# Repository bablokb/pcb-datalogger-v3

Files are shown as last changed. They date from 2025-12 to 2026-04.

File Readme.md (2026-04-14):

KiCAD-Designfiles for Version 3 PCB
===================================

Here are the KiCAD (v7) design-files for the Datalogger-V3-PCB.

The PCB supports a
[display-adapter](https://github.com/bablokb/pcb-datalogger-display-adapter)
connected with SURS-cables, or an [adapter connected with normal
DuPont-sockets](https://github.com/bablokb/pcb-datalogger-display-adapter-v2).

Schematic
---------

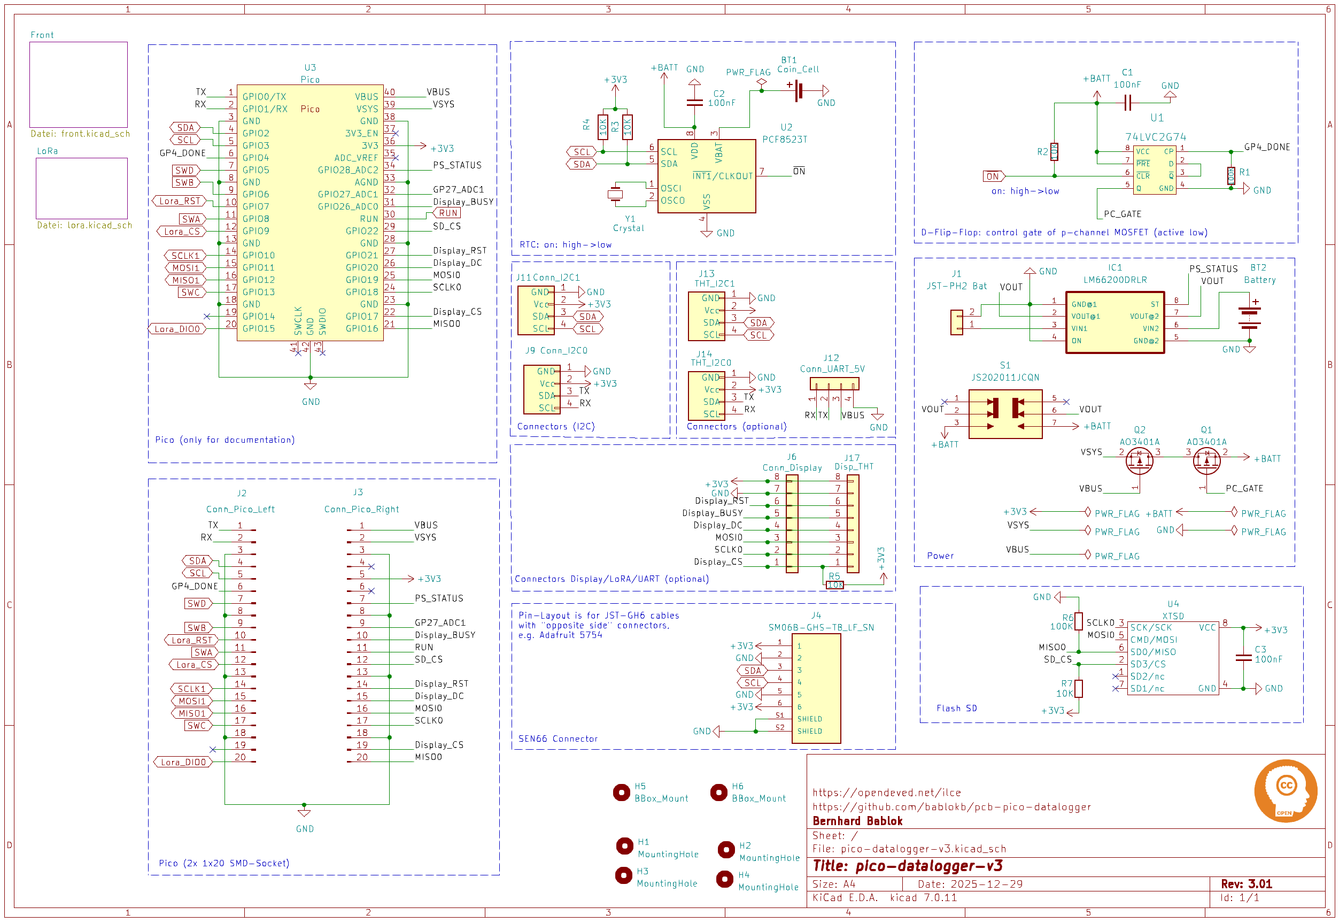
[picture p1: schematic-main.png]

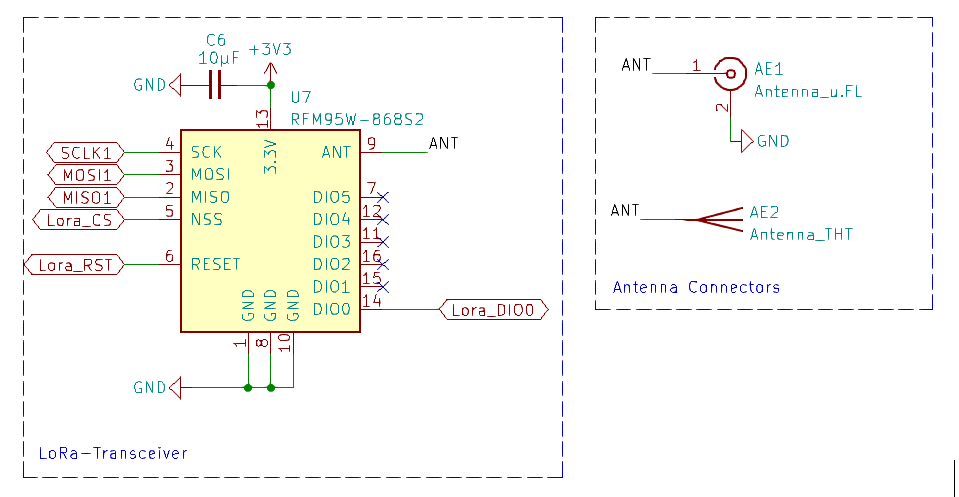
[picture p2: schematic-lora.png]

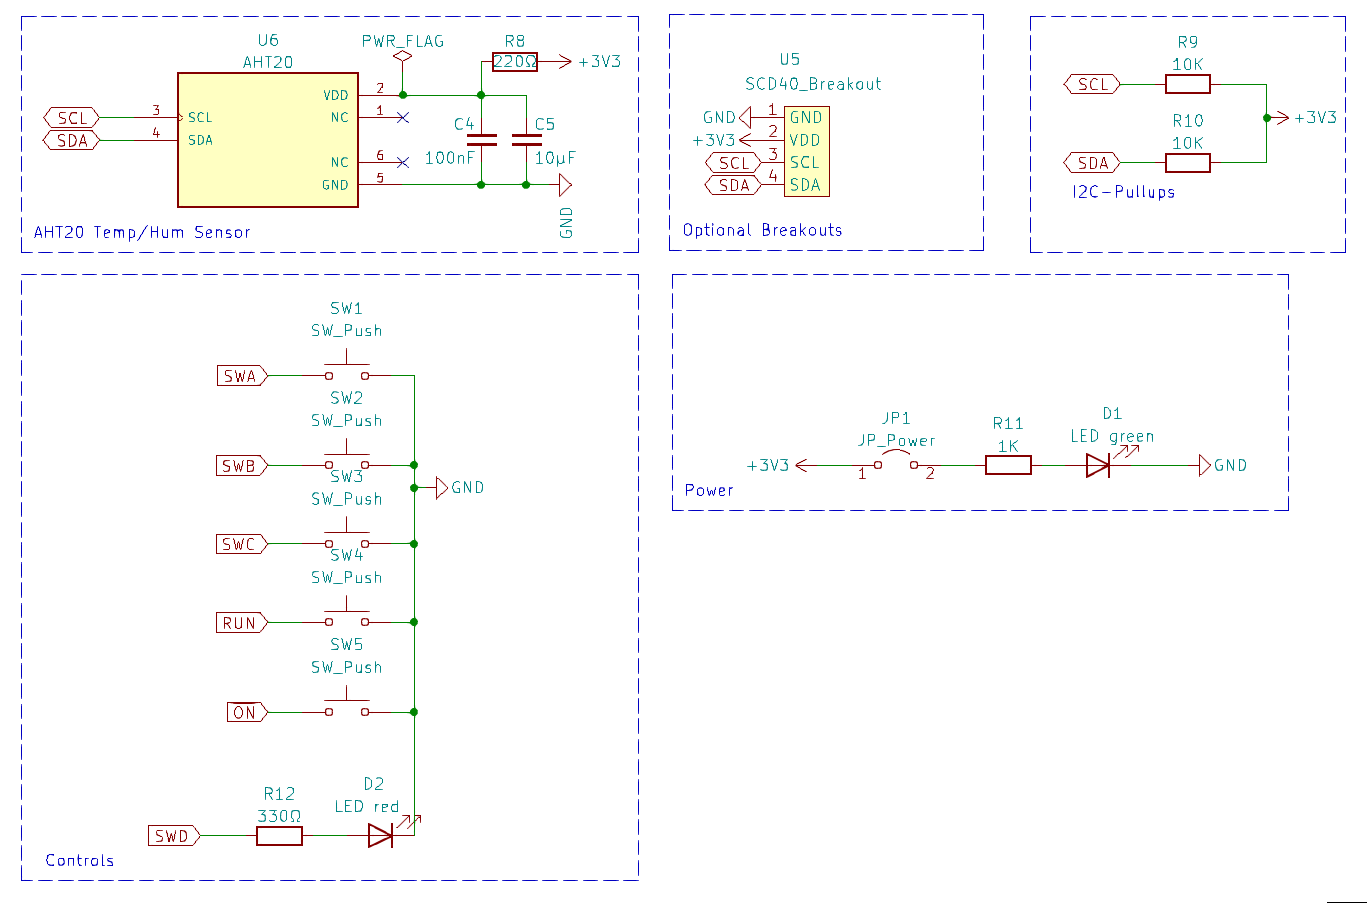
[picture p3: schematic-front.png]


Layout
------

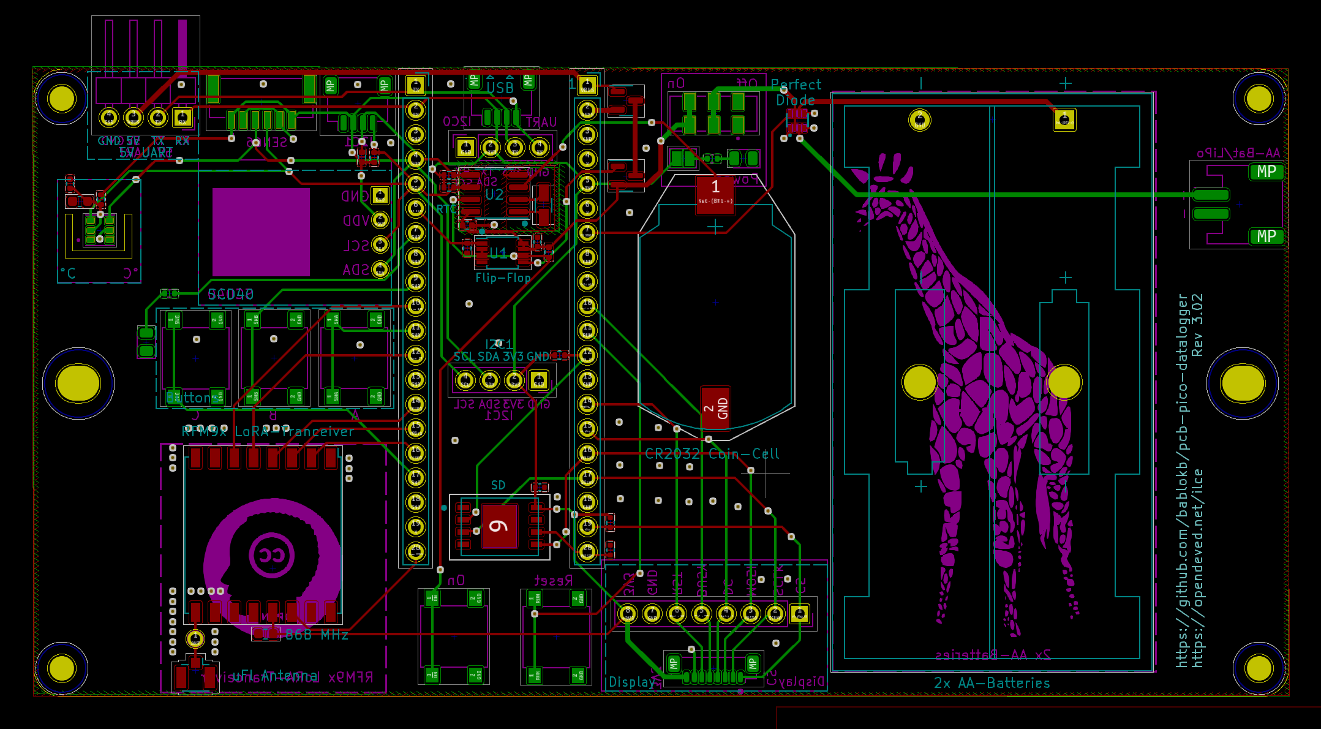
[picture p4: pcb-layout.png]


3D-Views
--------

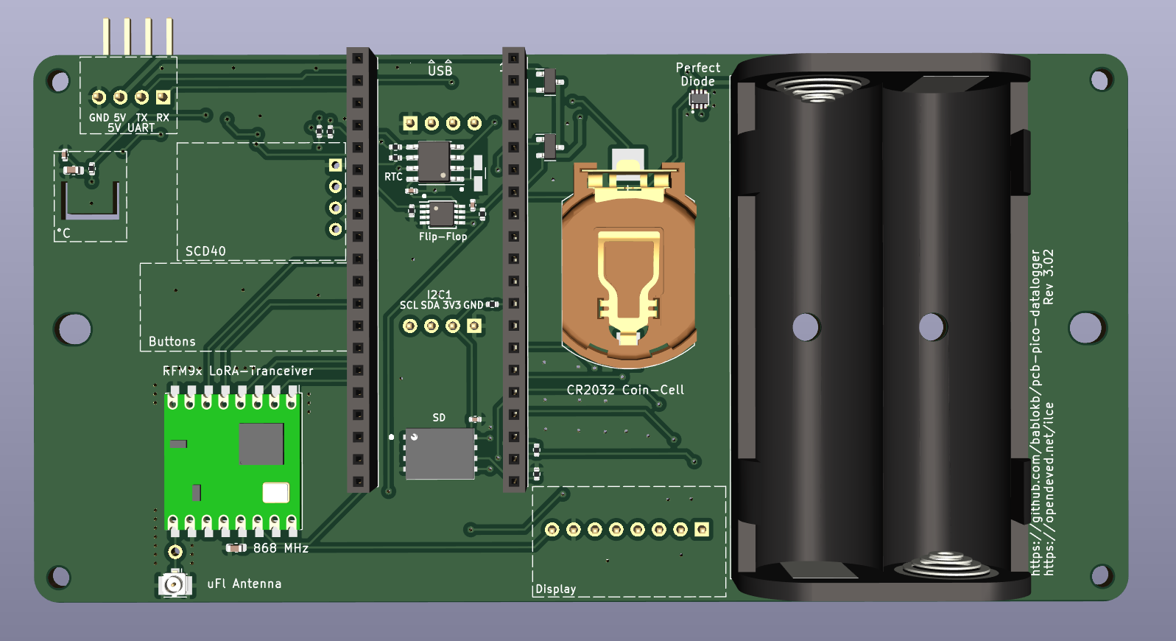
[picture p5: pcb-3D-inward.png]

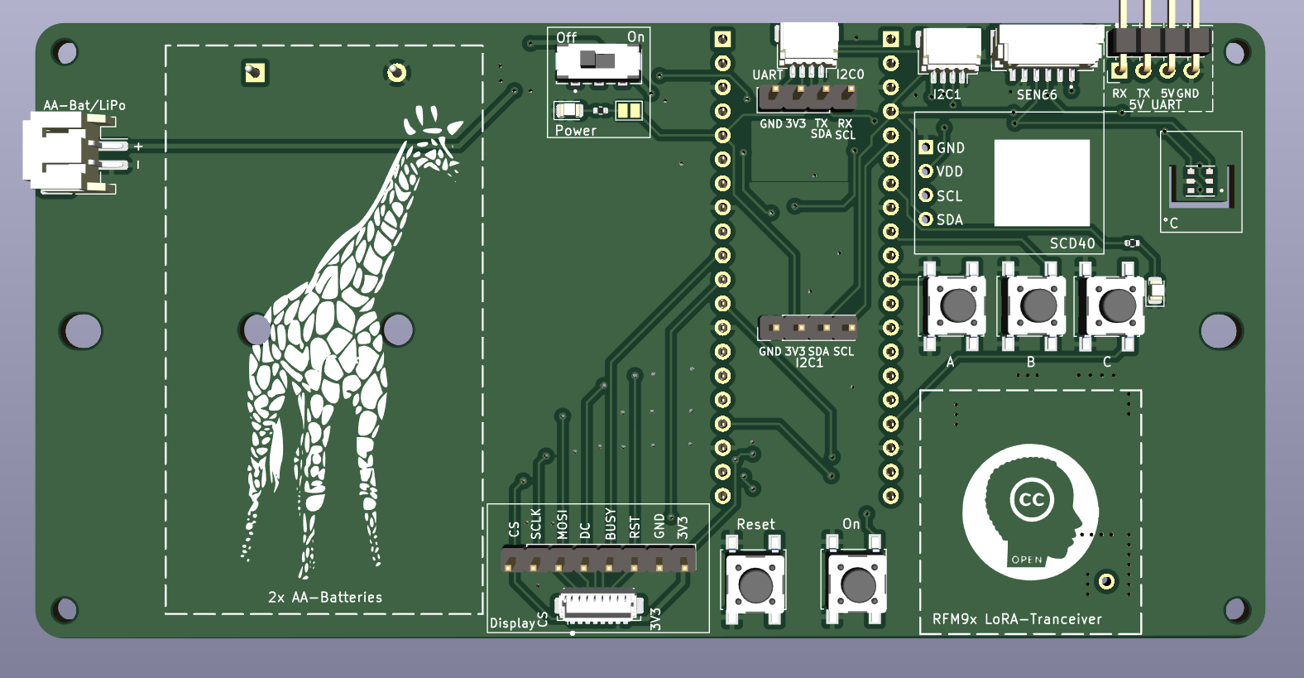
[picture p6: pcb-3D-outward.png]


Printed Case
------------

A printed case is available from <https://github.com/bablokb/3D-datalogger-v3-case>:



Together with a display:



License
-------

[![CC BY-SA 4.0][cc-by-sa-shield]][cc-by-sa]

This work is licensed under a
[Creative Commons Attribution-ShareAlike 4.0 International
License][cc-by-sa].

[][cc-by-sa]

[cc-by-sa]: http://creativecommons.org/licenses/by-sa/4.0/
[cc-by-sa-image]: https://licensebuttons.net/l/by-sa/4.0/88x31.png
[cc-by-sa-shield]:
https://img.shields.io/badge/License-CC%20BY--SA%204.0-lightgrey.svg

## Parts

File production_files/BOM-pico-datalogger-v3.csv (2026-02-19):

Comment | Designator | Footprint | LCSC
1K | R11 | R_0402_1005Metric | C11702
SM06B-GHS-TB_LF_SN | J4 | JST_SM06B-GHS-TB_LF_SN | C133065
AO3401A | Q1,Q2 | SOT-23 | C15127
100nF | C1,C2,C3,C4 | C_0402_1005Metric | C1525
Conn_I2C1 | J11,J9 | JST_SH_SM04B-SRSS-TB_1x04-1MP_P1.00mm_Horizontal | C160404
10µF | C5,C6 | C_0603_1608Metric | C19702
JS202011JCQN | S1 | SW_JS202011JCQN | C221665
SW_Push | SW1,SW2,SW3,SW4,SW5 | SW_SPST_B3S-1000 | C221869
LED green | D1 | LED_0805_2012Metric | C2297
220Ω | R8 | R_0402_1005Metric | C25091
330Ω | R12 | R_0402_1005Metric | C25104
100K | R1,R6 | R_0402_1005Metric | C25741
10K | R10,R2,R3,R4,R5,R7,R9 | R_0402_1005Metric | C25744
PCF8523T | U2 | SOIC-8_3.9x4.9mm_P1.27mm | C2651516
RFM95W-868S2 | U7 | HOPERF_RFM9XW_SMD | C2844472
JST-PH2 Bat | J1 | JST_PH_S2B-PH-SM4-TB_1x02-1MP_P2.00mm_Horizontal | C295747
AHT20 | U6 | AHT20 | C3012622
Battery | BT2 | BatteryHolder_Keystone_2462_2xAA | C3029547
Crystal | Y1 | Crystal_SMD_3215-2Pin_3.2x1.5mm | C32346
LM66200DRLR | IC1 | LM66200DRLR | C3235556
Conn_Pico_Left | J2,J3 | PinSocket_1x20_P2.54mm_Vertical | C429947
Conn_Display | J6 | JST_SUR_BM08B-SURS-TF_1x08-1MP_P0.80mm_Vertical | C5143489
74LVC2G74 | U1 | X2SON-8_1.4x1mm_P0.35mm | C548678
XTSD | U4 | XTSD | C7429710
LED red | D2 | LED_0805_2012Metric | C84256
Antenna_u.FL | AE1 | U.FL_Hirose_U.FL-R-SMT-1_Vertical | C88374
Coin_Cell | BT1 | CR2032_Holder | C964777

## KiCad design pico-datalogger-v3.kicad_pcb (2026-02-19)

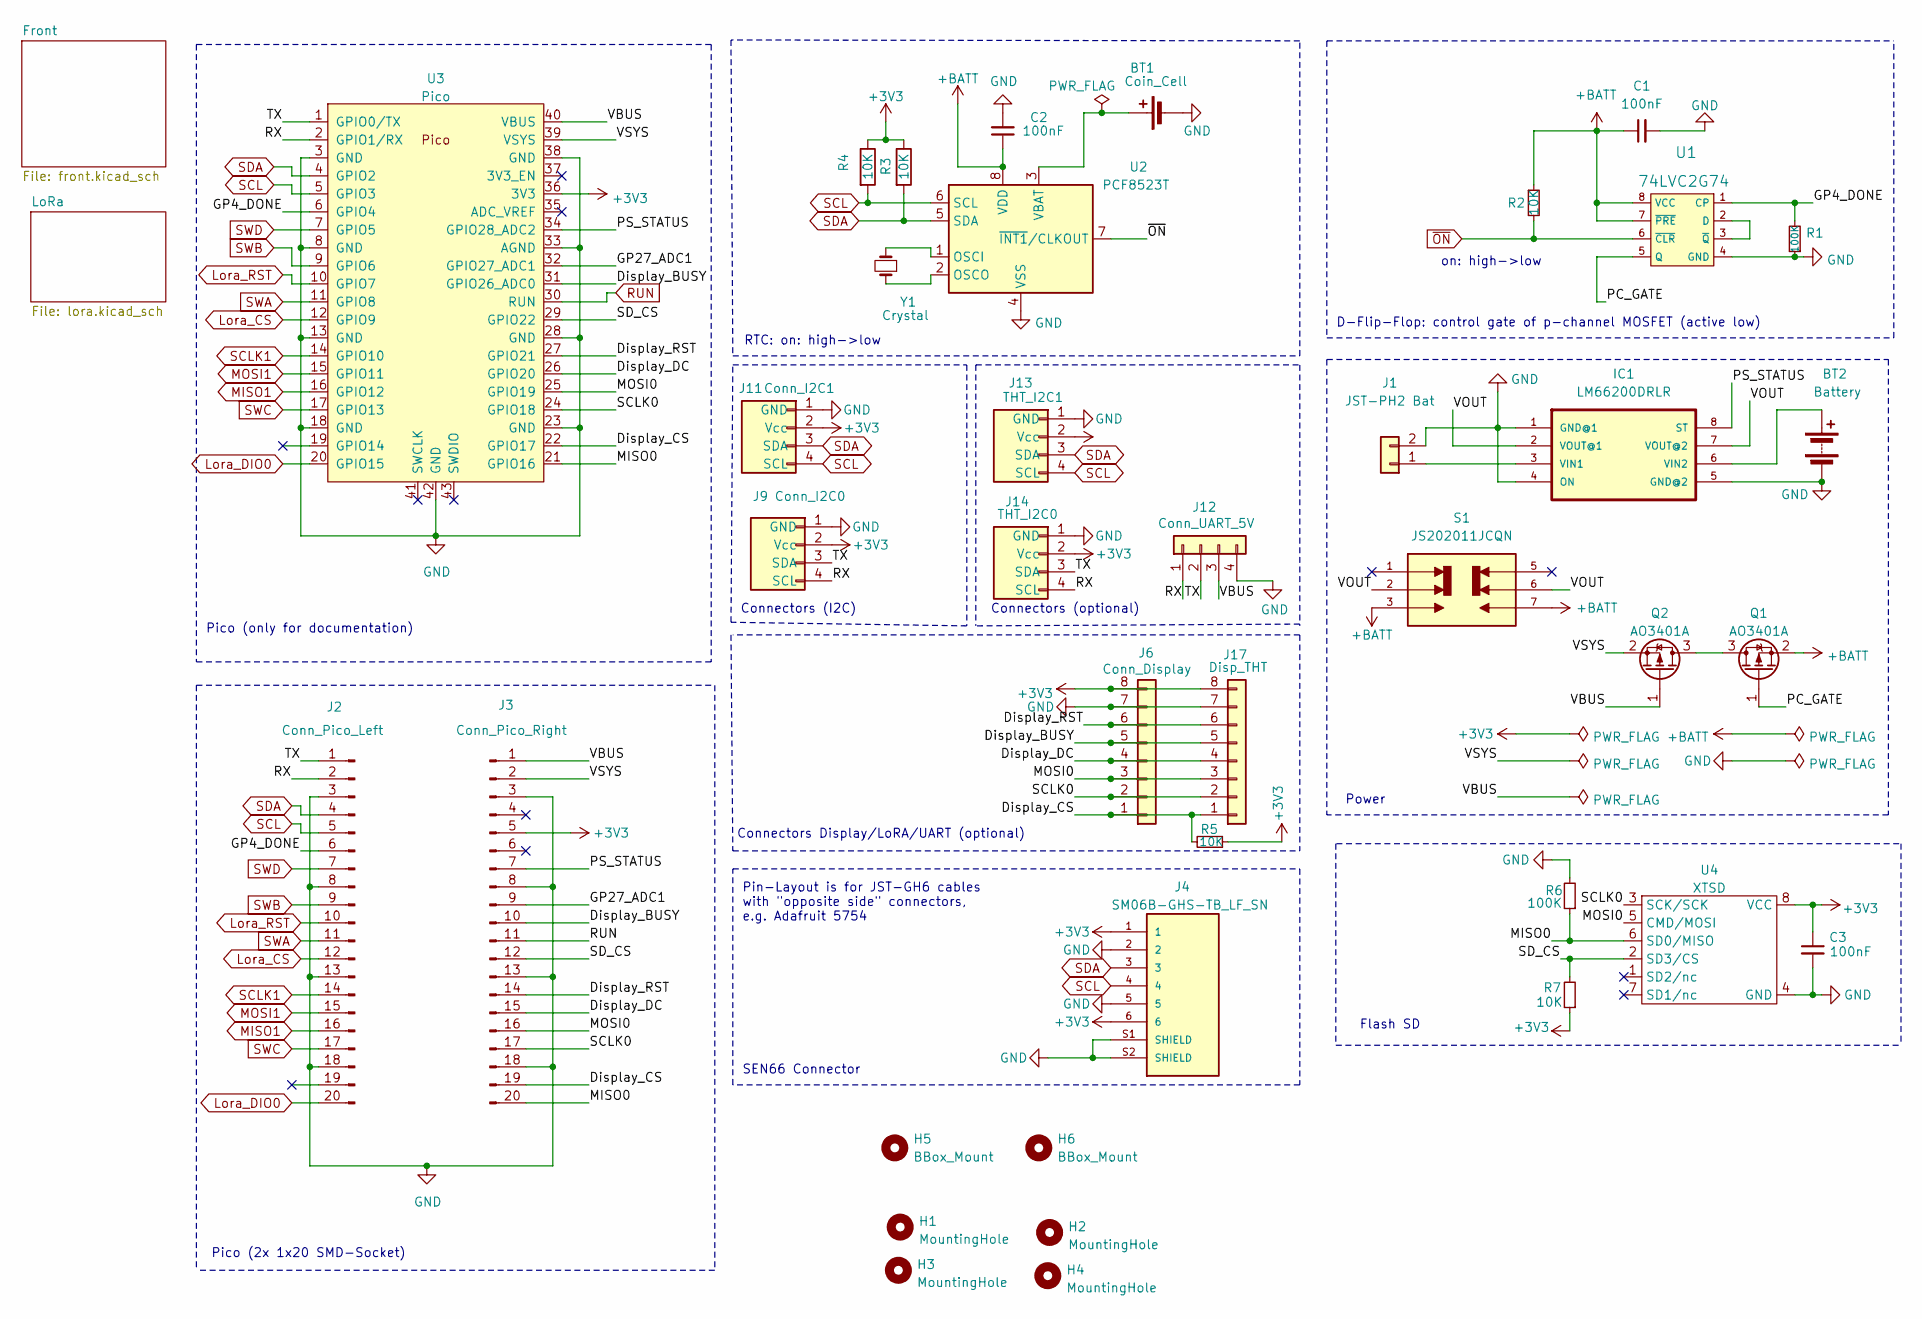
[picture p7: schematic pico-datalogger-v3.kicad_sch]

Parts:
BT1: Coin_Cell; CR2032_Holder; LCSC C964777
BT2: Battery; BatteryHolder_Keystone_2462_2xAA; LCSC C3029547
C1, C2, C3: 100nF; C_0402_1005Metric; LCSC C1525
H1, H2, H3, H4: MountingHole; MountingHole_2.5mm
H5, H6: BBox_Mount; MountingHole_3.5_slotted
IC1: LM66200DRLR; LCSC C3235556
J1: JST-PH2 Bat; JST_PH_S2B-PH-SM4-TB_1x02-1MP_P2.00mm_Horizontal; LCSC C295747
J2: Conn_Pico_Left; PinSocket_1x20_P2.54mm_Vertical; LCSC C429947
J3: Conn_Pico_Right; PinSocket_1x20_P2.54mm_Vertical; LCSC C429947
J4: SM06B-GHS-TB_LF_SN; JST_SM06B-GHS-TB_LF_SN; LCSC C133065
J6: Conn_Display; JST_SUR_BM08B-SURS-TF_1x08-1MP_P0.80mm_Vertical; LCSC C5143489
J9: Conn_I2C0; JST_SH_SM04B-SRSS-TB_1x04-1MP_P1.00mm_Horizontal; LCSC C160404
J11: Conn_I2C1; JST_SH_SM04B-SRSS-TB_1x04-1MP_P1.00mm_Horizontal; LCSC C160404
J12: Conn_UART_5V; PinHeader_1x04_P2.54mm_Horizontal
J13: THT_I2C1; PinHeader_1x04_P2.54mm_Vertical
J14: THT_I2C0; PinHeader_1x04_P2.54mm_Vertical
J17: Disp_THT; PinHeader_1x08_P2.54mm_Vertical
Q1, Q2: AO3401A; SOT-23; LCSC C15127
R1, R6: 100K; R_0402_1005Metric; LCSC C25741
R2, R3, R4, R5, R7: 10K; R_0402_1005Metric; LCSC C25744
S1: JS202011JCQN; SW_JS202011JCQN; LCSC C221665
U1: 74LVC2G74; X2SON-8_1.4x1mm_P0.35mm; MPN SN74HC74N; Digi-Key_PN 296-1602-5-ND
U2: PCF8523T; SOIC-8_3.9x4.9mm_P1.27mm; LCSC C2651516
U3: Pico; RPi_Pico_TH_nodbg
U4: XTSD; LCSC C7429710
Y1: Crystal; Crystal_SMD_3215-2Pin_3.2x1.5mm; LCSC C32346

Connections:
+3V3: C3.1, J3.5, J4.1, J4.6, J6.8, J9.2 (Vcc), J11.2 (Vcc), J13.2 (Vcc), J14.2 (Vcc), J17.8, R3.1, R4.1, R5.1, R7.1, U3.36 (3V3), U4.8 (VCC); also elsewhere on the board
+BATT: C1.1, C2.1, Q1.2 (S), R2.1, S1.3, S1.7, U1.7 (~PRE), U1.8 (VCC), U2.8 (VDD)
/Display_BUSY: J3.10, J6.5, J17.5, U3.31 (GPIO26_ADC0)
/Display_CS: J3.19, J6.1, J17.1, R5.2, U3.22 (GPIO17)
/Display_DC: J3.15, J6.4, J17.4, U3.26 (GPIO20)
/Display_RST: J3.14, J6.6, J17.6, U3.27 (GPIO21)
/GP4_DONE: J2.6, R1.2, U1.1 (CP), U3.6 (GPIO4)
/GP27_ADC1: J3.9, U3.32 (GPIO27_ADC1)
/MISO0: J3.20, R6.1, U3.21 (GPIO16), U4.6 (SD0/MISO)
/MOSI0: J3.16, J6.3, J17.3, U3.25 (GPIO19), U4.5 (CMD/MOSI)
/PC_GATE: Q1.1 (G), U1.5 (Q)
/PS_STATUS: IC1.8 (ST), J3.7, U3.34 (GPIO28_ADC2)
/RX: J2.2, J9.4 (SCL), J12.1, J14.4 (SCL), U3.2 (GPIO1/RX)
/SCLK0: J3.17, J6.2, J17.2, U3.24 (GPIO18), U4.3 (SCK/SCK)
/SD_CS: J3.12, R7.2, U3.29 (GPIO22), U4.2 (SD3/CS)
/TX: J2.1, J9.3 (SDA), J12.2, J14.3 (SDA), U3.1 (GPIO0/TX)
/VBUS: J3.1, J12.3, Q2.1 (G), U3.40 (VBUS)
/VOUT: IC1.2 (VOUT@1), IC1.7 (VOUT@2), S1.2, S1.6
/VSYS: J3.2, Q2.2 (S), U3.39 (VSYS)
GND: BT1.2 (-), BT2.2 (-), C1.2, C2.2, C3.2, IC1.1 (GND@1), IC1.4 (ON), IC1.5 (GND@2), J1.2, J2.3, J2.8, J2.13, J2.18, J3.3, J3.8, J3.13, J3.18, J4.2, J4.5, J4.S1 (SHIELD), J4.S2 (SHIELD), J6.7, J9.1 (GND), J11.1 (GND), J12.4, J13.1 (GND), J14.1 (GND), J17.7, R1.1, R6.2, U1.4 (GND), U2.4 (VSS), U3.3 (GND), U3.8 (GND), U3.13 (GND), U3.18 (GND), U3.23 (GND), U3.28 (GND), U3.33 (AGND), U3.38 (GND), U3.42 (GND), U4.4 (GND); also elsewhere on the board
Lora_CS: J2.12, U3.12 (GPIO9); also elsewhere on the board
Lora_DIO0: J2.20, U3.20 (GPIO15); also elsewhere on the board
Lora_RST: J2.10, U3.10 (GPIO7); also elsewhere on the board
MISO1: J2.16, U3.16 (GPIO12); also elsewhere on the board
MOSI1: J2.15, U3.15 (GPIO11); also elsewhere on the board
unnamed: BT1.1 (+), U2.3 (VBAT)
unnamed: BT2.1 (+), IC1.6 (VIN2)
unnamed: IC1.3 (VIN1), J1.1
unnamed: Q1.3 (D), Q2.3 (D)
unnamed: U1.2 (D), U1.3 (~Q)
unnamed: U2.1 (OSCI), Y1.2
unnamed: U2.2 (OSCO), Y1.1
RUN: J3.11; also elsewhere on the board
SCL: J2.5, J4.4, J11.4 (SCL), J13.4 (SCL), R4.2, U2.6 (SCL), U3.5 (GPIO3); also elsewhere on the board
SCLK1: J2.14, U3.14 (GPIO10); also elsewhere on the board
SDA: J2.4, J4.3, J11.3 (SDA), J13.3 (SDA), R3.2, U2.5 (SDA), U3.4 (GPIO2); also elsewhere on the board
SWA: J2.11, U3.11 (GPIO8); also elsewhere on the board
SWB: J2.9, U3.9 (GPIO6); also elsewhere on the board
SWC: J2.17, U3.17 (GPIO13); also elsewhere on the board
SWD: J2.7, U3.7 (GPIO5); also elsewhere on the board
~ON: R2.2, U1.6 (~CLR), U2.7 (~INT1/CLKOUT); also elsewhere on the board

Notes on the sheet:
on: high->low
D-Flip-Flop: control gate of p-channel MOSFET (active low)
Connectors Display/LoRA/UART (optional)
Pico (only for documentation)
Power
Pico (2x 1x20 SMD-Socket)
SEN66 Connector
RTC: on: high->low
Connectors (optional)
Pin-Layout is for JST-GH6 cables with "opposite side" connectors, e.g. Adafruit 5754
Connectors (I2C)
Flash SD

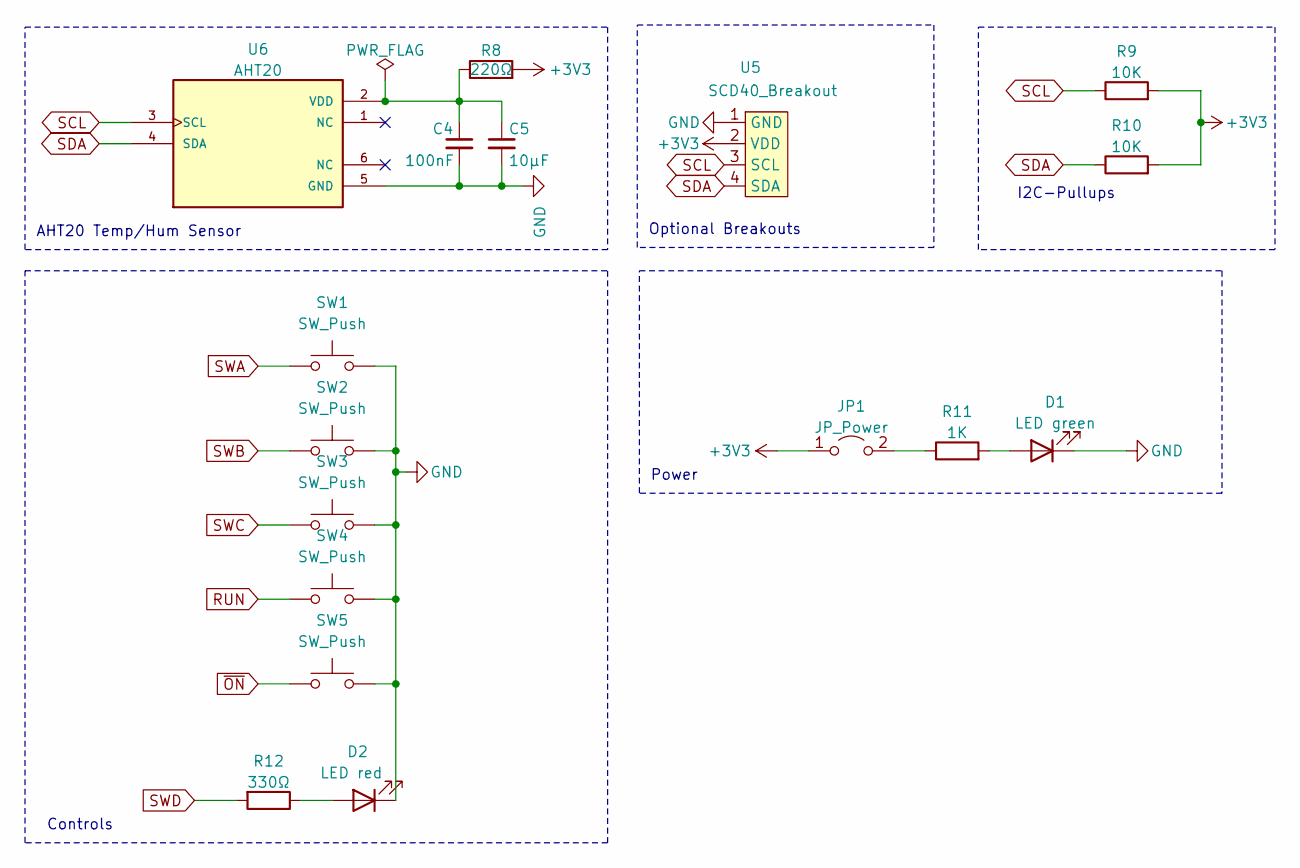
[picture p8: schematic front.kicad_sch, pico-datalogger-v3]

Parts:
C4: 100nF; C_0402_1005Metric; LCSC C1525
C5: 10µF; C_0603_1608Metric; LCSC C19702
D1: LED green; LED_0805_2012Metric; LCSC C2297
D2: LED red; LED_0805_2012Metric; LCSC C84256
JP1: JP_Power; SolderJumper-2_P1.3mm_Open_Pad1.0x1.5mm
R8: 220Ω; R_0402_1005Metric; LCSC C25091
R9, R10: 10K; R_0402_1005Metric; LCSC C25744
R11: 1K; R_0402_1005Metric; LCSC C11702
R12: 330Ω; R_0402_1005Metric; LCSC C25104
SW1, SW2, SW3, SW4, SW5: SW_Push; SW_SPST_B3S-1000; LCSC C221869
U5: SCD40_Breakout
U6: AHT20; LCSC C3012622

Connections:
+3V3: JP1.1 (A), R8.2, R9.2, R10.2, U5.2 (VDD); also elsewhere on the board
GND: C4.2, C5.2, D1.1 (K), D2.1 (K), SW1.2, SW2.2, SW3.2, SW4.2, SW5.2, U5.1 (GND), U6.5 (GND); also elsewhere on the board
unnamed: D1.2 (A), R11.2
unnamed: D2.2 (A), R12.1
unnamed: JP1.2 (B), R11.1
unnamed: C4.1, C5.1, R8.1, U6.2 (VDD)
RUN: SW4.1; also elsewhere on the board
SCL: R9.1, U5.3 (SCL), U6.3 (SCL); also elsewhere on the board
SDA: R10.1, U5.4 (SDA), U6.4 (SDA); also elsewhere on the board
SWA: SW1.1; also elsewhere on the board
SWB: SW2.1; also elsewhere on the board
SWC: SW3.1; also elsewhere on the board
SWD: R12.2; also elsewhere on the board
~ON: SW5.1; also elsewhere on the board

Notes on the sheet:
Optional Breakouts
AHT20 Temp/Hum Sensor
Power
I2C-Pullups
Controls

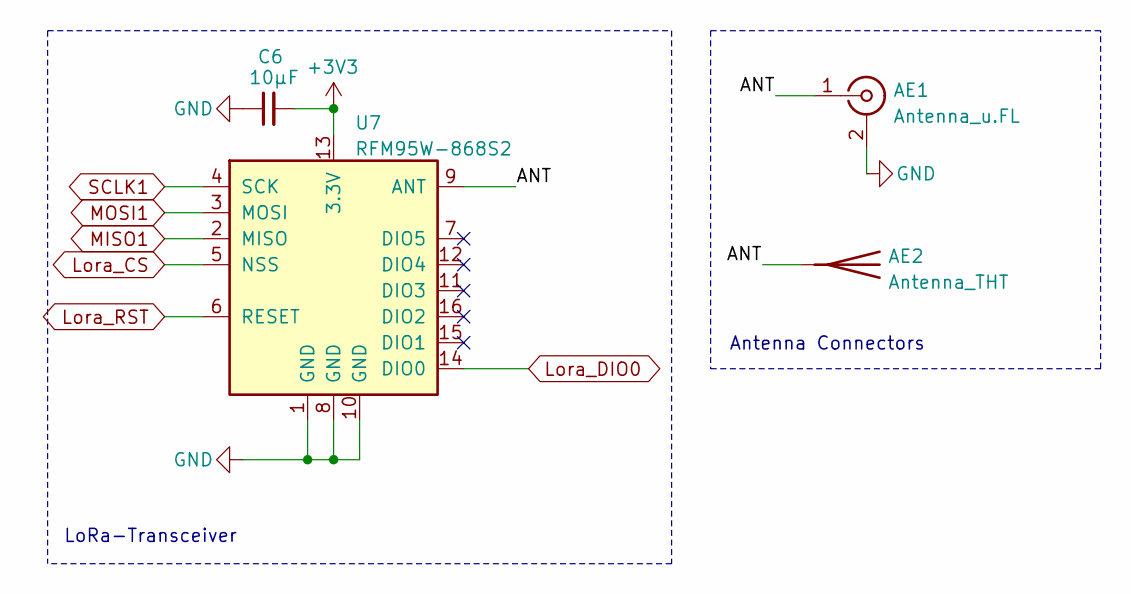
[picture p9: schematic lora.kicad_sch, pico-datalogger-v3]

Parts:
AE1: Antenna_u.FL; U.FL_Hirose_U.FL-R-SMT-1_Vertical; LCSC C88374
AE2: Antenna_THT
C6: 10µF; C_0603_1608Metric; LCSC C19702
U7: RFM95W-868S2; HOPERF_RFM9XW_SMD; LCSC C2844472

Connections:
+3V3: C6.2, U7.13 (3.3V); also elsewhere on the board
/LoRa/ANT: AE1.1 (In), AE2.1 (A), U7.9 (ANT)
GND: AE1.2 (Ext), C6.1, U7.1 (GND), U7.8 (GND), U7.10 (GND); also elsewhere on the board
Lora_CS: U7.5 (NSS); also elsewhere on the board
Lora_DIO0: U7.14 (DIO0); also elsewhere on the board
Lora_RST: U7.6 (RESET); also elsewhere on the board
MISO1: U7.2 (MISO); also elsewhere on the board
MOSI1: U7.3 (MOSI); also elsewhere on the board
SCLK1: U7.4 (SCK); also elsewhere on the board

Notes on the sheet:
Antenna Connectors
LoRa-Transceiver

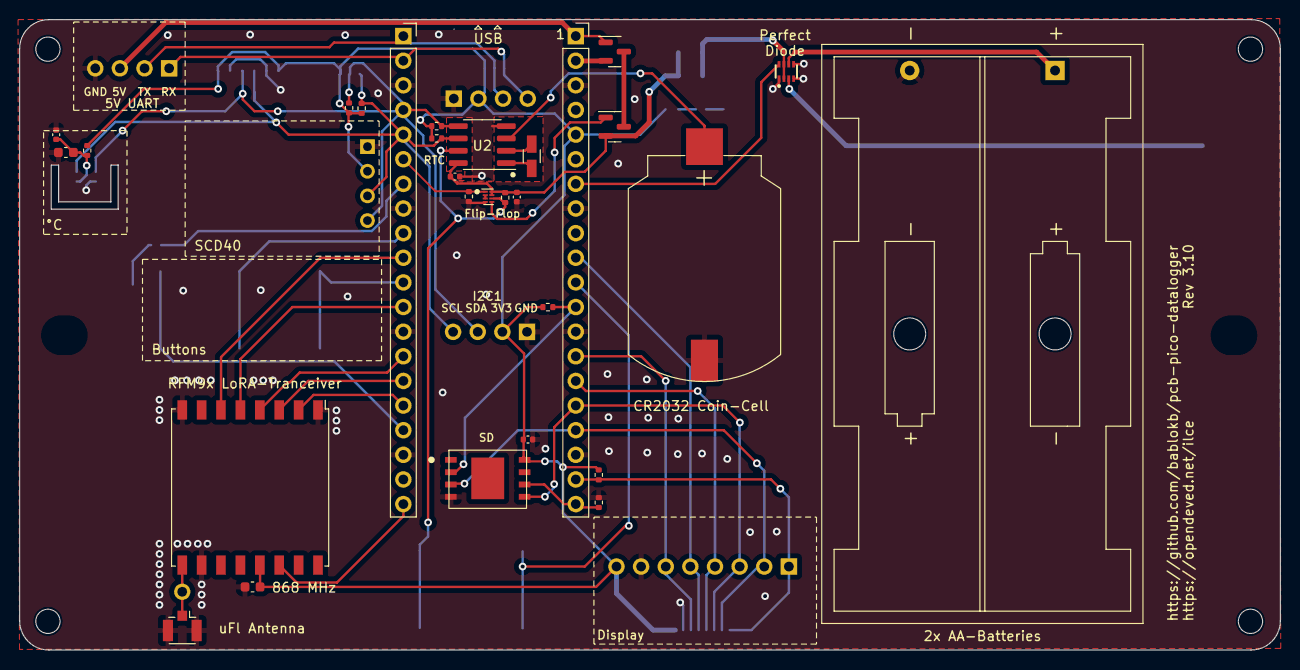
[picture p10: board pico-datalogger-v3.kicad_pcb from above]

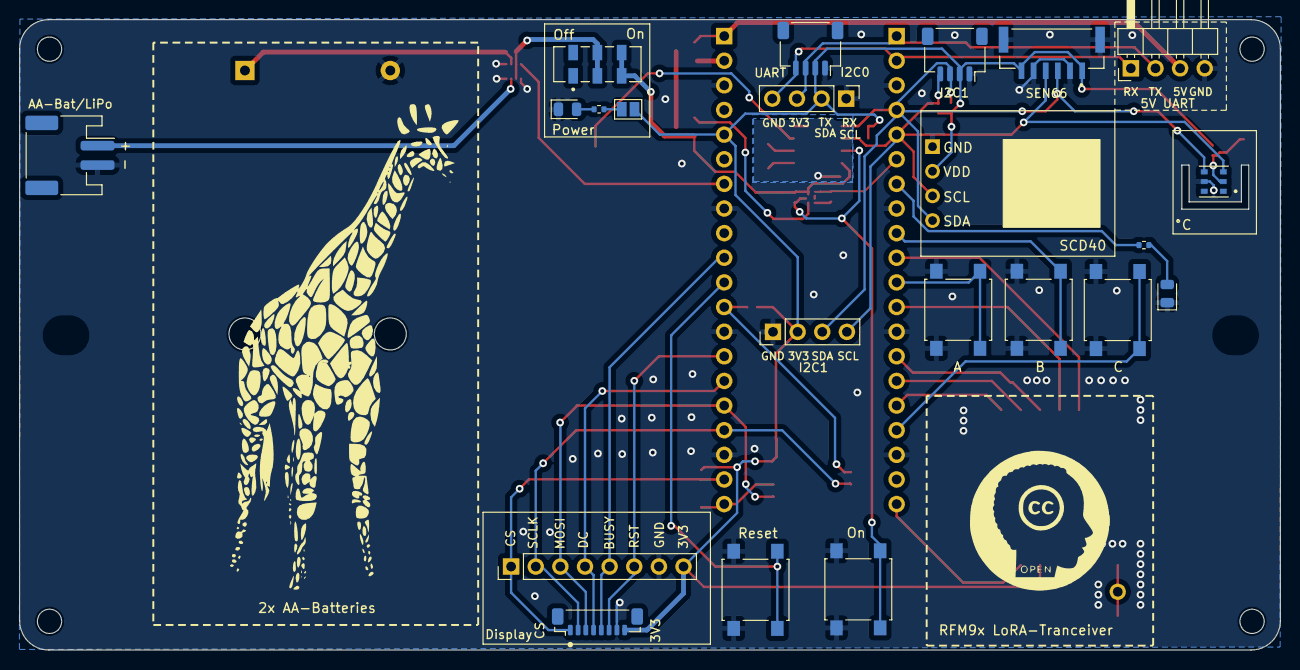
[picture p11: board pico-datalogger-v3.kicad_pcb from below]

Board: 2 copper layers, 130.0 x 65.0 mm, 58 parts (22 on the bottom side), 45 nets.

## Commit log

2025-11-10 initial version of v3 PCB
    [front.kicad_sch, lora.kicad_sch, pico-datalogger-v3.kicad_pcb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]
2025-11-12 fix pin-order for SEN66-connector
    [front.kicad_sch, lora.kicad_sch, pico-datalogger-v3.kicad_pcb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]
2025-11-12 switch to user:JST-PH2
    [pico-datalogger-v3.kicad_pcb, pico-datalogger-v3.kicad_sch]
2025-11-12 switch to user:JST-SH4
    [pico-datalogger-v3.kicad_pcb, pico-datalogger-v3.kicad_sch]
2025-11-12 update footprint RFM96x
    [pico-datalogger-v3.kicad_pcb]
2025-11-12 switch to user:SW_PUSH
    [front.kicad_sch, pico-datalogger-v3.kicad_pcb]
2025-11-12 switch to user:JST_SUR_BM08B-SURS-TF_1x08-1MP_P0.80mm_Vertical
    [pico-datalogger-v3.kicad_pcb, pico-datalogger-v3.kicad_sch]
2025-11-12 flipped I2C0-THT to back-side
    [pico-datalogger-v3.kicad_pcb]
2025-11-12 improved silkscreen
    [pico-datalogger-v3.kicad_pcb]
2025-11-13 move AA-holder away from mounting-hole
    [pico-datalogger-v3.kicad_pcb]
2025-11-18 connect status-pin of diode to GP28
    [front.kicad_sch, lora.kicad_sch, pico-datalogger-v3.kicad_sch]
2025-11-18 initial routing of power and I2C-devices
    [pico-datalogger-v3.kicad_pcb]
2025-11-18 initial routing display-connector, on/rst buttons
    [pico-datalogger-v3.kicad_pcb]
2025-11-19 swapped SWA/SWB with LoRa-RST/LoRa-CS; initial routing of LoRa and buttons
    [front.kicad_sch, lora.kicad_sch, pico-datalogger-v3.kicad_pcb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]
2025-11-20 swapped additional pins to simplify routing
    [front.kicad_sch, lora.kicad_sch, pico-datalogger-v3.kicad_pcb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]
2025-11-21 added GND-vias for LoRa
    [pico-datalogger-v3.kicad_pcb]
2025-11-21 fine tune AHT20 layout and add cutout
    [pico-datalogger-v3.kicad_pcb]
2025-11-21 fixes for production files
    [front.kicad_sch, lora.kicad_sch, pico-datalogger-v3.kicad_pcb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]
2025-11-21 added preliminary production-files
    [BOM-pico-datalogger-v3.csv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]
2025-11-21 changes due to production-file generation
    [pico-datalogger-v3.kicad_pcb]
2025-11-30 use 868-version of LoRa-chip (for iteration-1)
    [BOM-pico-datalogger-v3.csv]
2025-12-12 fixed 3D model for battery-holder
    [pico-datalogger-v3.kicad_pcb]
2026-01-03 updated production-files for datalogger-v3 and images
    [BOM-pico-datalogger-v3.csv, pico-datalogger-v3.kicad_pcb, pico-datalogger-v3.kicad_sch]
2026-01-15 updated production-files for datalogger-v3 (with rfm95-868)
    [BOM-pico-datalogger-v3.csv, lora.kicad_sch, pico-datalogger-v3.kicad_pcb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]
2026-02-19 Rev. 3.10: use XSON-8 package for flip-flop
    [BOM-pico-datalogger-v3.csv, pico-datalogger-v3.kicad_pcb, pico-datalogger-v3.kicad_sch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]
2026-03-13 removed temporary file
    [pico-datalogger-v3-all-pos.csv]
2026-04-14 link to display-adapters and 3D-printed cases
2026-05-06 added no-header BOM for JLCPCB BOM-Tool
    [BOM-no-header-pico-datalogger-v3.csv]
